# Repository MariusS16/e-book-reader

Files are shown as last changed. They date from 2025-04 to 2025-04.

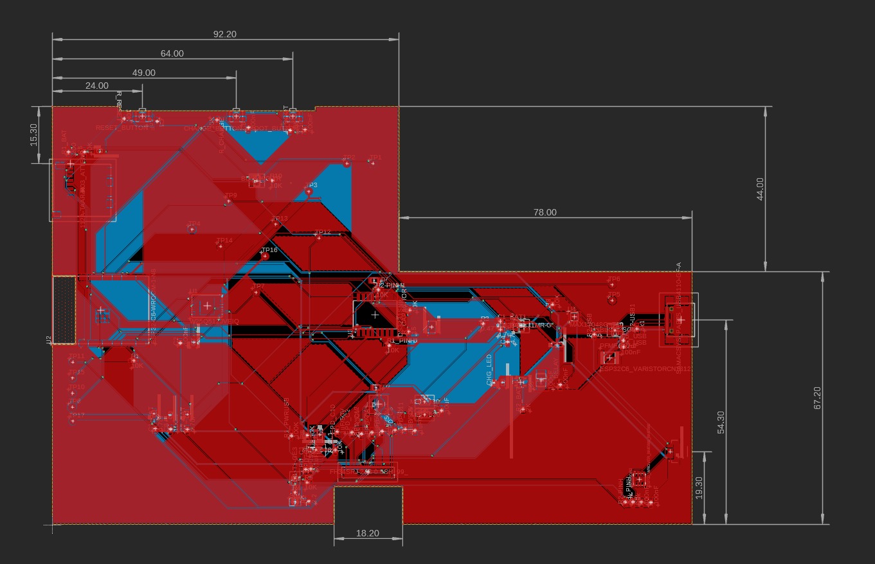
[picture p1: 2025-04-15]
Images/finalpcb.jpg

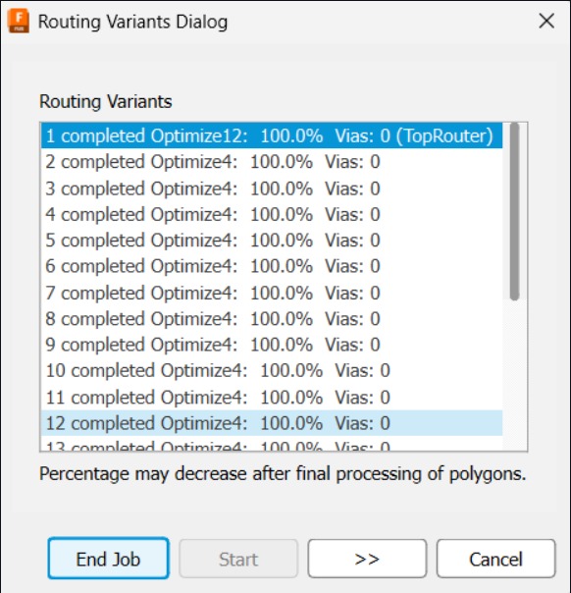
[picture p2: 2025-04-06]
Images/img4.jpg

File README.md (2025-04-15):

# README - OpenBook E-Reader

**Autor: Slincu Marius**

## Prezentare Generală

OpenBook este un e-reader open-source bazat pe microcontrollerul ESP32-C6. Dispozitivul integrează un ecran e-paper de 7.5 inch, un senzor de mediu (BME680), un sistem de monitorizare a bateriei, precum și conectivitate Wi-Fi și USB-C. Acest fisier descrie arhitectura hardware a proiectului, componentele principale și modul în care acestea sunt interconectate.

---

## Diagramă de Bloc

```

                +---------------------------+
                |     USB-C Connector       |
                | (USB Data ↔ ESP32 USB)    |
                | (ESD & Termination Prot.) |
                +-------------+-------------+
                              |
                              v
                +--------------------------+
                |       Charging IC        |<-- USB-C Power
                +-------------+------------+
                              |
                              v
                +--------------------------+
                |         Battery          |
                +-------------+------------+
                              |
                              v
                +--------------------------+
                |           LDO            |
                |       (3.3V Reg)         |
                +-------------+------------+
                              |
                              v
                      +--------------+
                      |    ESP32-C6   |
                      +------+--------+
                             |
      +----------------------+-------------------------+
      |                      |                         |
      v                      v                         v
+-----------+       +----------------+         +-----------------+
|  Display  |<----->|     BME688     |<------->| Tactile Buttons |
| (SPI 4W)  |       |   (I2C + PU)   |         |  (GPIO + RC)     |
+-----------+       +----------------+         +-----------------+
```

---
## Detalii Hardware

### ESP32-C6-WROOM-1-N8

- **Rol**: Componenta centrală de control, responsabilă pentru conectivitatea wireless și interacțiunea cu perifericele.
- **Interfețe disponibile**:
  - SPI: Utilizată pentru comunicarea cu ecranul e-paper, memoria Flash și cardul Micro SD.
  - I2C: Pentru conectarea senzorului BME680, monitorului de baterie (MAX17048) și ceasului RTC (DS3231).
  - GPIO: Utilizați pentru butoane de control și semnalizare prin LED-uri.
  - UART: Dedicat depanării și comunicației seriale.
- **Specificații tehnice**: Tactat la 160MHz, 512KB SRAM, 8MB memorie Flash integrată.

### Senzor BME680

- **Rol**: Oferă măsurători precise pentru temperatură, umiditate, presiune atmosferică și calitatea aerului.
- **Interfață**: Comunicare prin magistrala I2C cu viteză de 400kHz.
- **Eficiență energetică**: Consumă sub 1mA în funcționare și sub 1µA în repaus.

### Sistem de Alimentare

- **Baterie**: Acumulator Li-Po de 2500mAh, 3.7V.
- **Încărcare**: Controlată de MCP73831 prin portul USB-C, cu un curent maxim de 1A.
- **Monitorizare**: Realizată cu ajutorul cipului MAX17048, prin I2C.
- **Profil de consum**:
  - În activitate (Wi-Fi activ și ecran actualizat): ~150mA.
  - În standby (ecran static, fără activitate radio): ~10mA.
  - În modul deep sleep: >50µA.
  - **Autonomie estimată**: ~250 de ore la un consum mediu de 10mA.

### Butoane de Navigare

- Folosește butoane tactile Panasonic EVQPUJ02K, fiecare cu rezistență pull-up de 10KΩ.

### USB-C

- **Funcții**: Utilizat pentru încărcare (5V/1A) și transfer de date (USB 2.0).
- **Protecție**: Diode ESD (USBLC6-2SC6Y) pentru protejarea la supratensiuni.

---
# Lista de Componente (BOM)

Tabelul de mai jos prezintă componentele folosite în proiect:
| Component | Buy | Datasheet |
| --- | --- | --- |
| PFMF.050.1 | [Retailer](https://ro.mouser.com/ProductDetail/Schurter/PFMF.050.2?qs=1auRipcfynCums5v1iucSA%3D%3D) |  [Datasheet](https://ro.mouser.com/datasheet/2/358/typ_PFMF-1275918.pdf) |
| USB4110-GF-A | [Retailer](https://ro.mouser.com/ProductDetail/GCT/USB4110-GF-A?qs=KUoIvG%2F9IlYiZvIXQjyJeA%3D%3D) | [Datasheet](https://ro.mouser.com/datasheet/2/837/GCT_USB4110_Product_Drawing___20k_cycles-3455479.pdf) |
| USBLC6-2SC6Y | [Retailer](https://ro.mouser.com/ProductDetail/STMicroelectronics/USBLC6-2SC6Y?qs=gNDSiZmRJS%2FOgDexvXkdow%3D%3D) | [Datasheet](https://ro.mouser.com/datasheet/2/389/usblc6_2sc6y-1852505.pdf) |
| SD0805S020S1R0 | [Retailer](https://ro.mouser.com/ProductDetail/KYOCERA-AVX/SD0805S020S1R0?qs=jCA%252BPfw4LHbpkAoSnwrdjw%3D%3D) | [Datasheet](https://ro.mouser.com/datasheet/2/40/schottky-3165252.pdf) |
| DMG2305UX-7 | [Retailer](https://ro.mouser.com/ProductDetail/Diodes-Incorporated/DMG2305UX-7?qs=L1DZKBg7t5F%2FNBHrjfxC%252Bg%3D%3D) | [Datasheet](https://www.diodes.com/assets/Datasheets/DMG2305UX.pdf) |
| XC6220A331MR-G | [Retailer](https://ro.mouser.com/ProductDetail/Torex-Semiconductor/XC6220A331MR-G?qs=AsjdqWjXhJ8ZSWznL1J0gg%3D%3D) | [Datasheet](https://ro.mouser.com/datasheet/2/760/xc6220-3371556.pdf) |
| Condensator 100 uF TANT | [Retailer](https://ro.mouser.com/ProductDetail/KYOCERA-AVX/TAJW107M010RNJ?qs=Wtp%252Bf%2FAeVqIH8v1VxV%252B1Rg%3D%3D) | [Datasheet](https://ro.mouser.com/datasheet/2/40/TAJ-3165264.pdf) |
| 112A-TAAR-R03_ATTEND | [Retailer](https://www.digikey.ro/en/products/detail/attend-technology/112A-TAAR-R03/17633923) | [Datasheet](https://www.attend.com.tw/data/download/file/112A-TAAR-R03_Spec.pdf)
| ESP32-C6-WROOM-1-N8 | [Retailer](https://ro.mouser.com/ProductDetail/Espressif-Systems/ESP32-C6-WROOM-1-N8?qs=8Wlm6%252BaMh8ST02Gmwp74cw%3D%3D) | [Datasheet](https://ro.mouser.com/datasheet/2/891/Espressif_ESP32_C6_WROOM_1__Datasheet_V0_1_PRELIMI-3239987.pdf) |
| MCP73831 | [Retailer](https://ro.mouser.com/ProductDetail/Microchip-Technology/MCP73831T-2ACI-OT?qs=yUQqVecv4qvbBQBGbHx0Mw%3D%3D) | [Datasheet](https://ro.mouser.com/datasheet/2/268/MCP73831_Family_Data_Sheet_DS20001984H-3441711.pdf) |
| CHG_LED | [Retailer](https://store.comet.srl.ro/Catalogue/Product/40478/) | [Datasheet](https://www.snapeda.com/parts/KP-1608SURCK/Kingbright/datasheet/) |
| SI1308EDL-T1-GE3 | [Retailer](https://ro.mouser.com/ProductDetail/Vishay-Semiconductors/SI1308EDL-T1-GE3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) | [Datasheet](https://www.vishay.com/doc?63399) |
| MBR0530 | [Retailer](https://ro.mouser.com/ProductDetail/Micro-Commercial-Components-MCC/MBR0530-T?qs=9VyI4qLX4NTSXkb9ynzJnA%3D%3D) | [Datasheet](https://ro.mouser.com/datasheet/2/258/mcc_mbr0520~mbr0560sod123-1179695.pdf) |
| L1 | [Retailer](https://ro.mouser.com/ProductDetail/Wurth-Elektronik/744043680?qs=PGXP4M47uW6VkZq%252BkzjrHA%3D%3D) | [Datasheet](https://www.we-online.com/components/products/datasheet/744043680.pdf) |
| FH34SRJ-24S-0.5SH_99_ | [Retailer](https://ro.mouser.com/ProductDetail/Hirose-Connector/FH34SRJ-24S-0.5SH99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) | [Datasheet](https://ro.mouser.com/datasheet/2/185/FH34SRJ_24S_0_5SH_99__CL0580_1255_6_99_2DDrawing_0-1615044.pdf) |
| BME688 | [Retailer](https://ro.mouser.com/ProductDetail/Bosch-Sensortec/BME688?qs=IS%252B4QmGtzzqQoVDscqwx3A%3D%3D) | [Datasheet](https://ro.mouser.com/datasheet/2/783/bst_bme688_fl000-2307034.pdf) |
| BD5229G-TR | [Retailer](https://ro.mouser.com/ProductDetail/ROHM-Semiconductor/BD5229G-TR?qs=4kLU8WoGk0vvnhrrYwdszw%3D%3D) | [Datasheet](https://fscdn.rohm.com/en/products/databook/datasheet/ic/power/voltage_detector/bd52xxg-e.pdf) |
| Button | [Retailer](https://ro.mouser.com/ProductDetail/CK/KMR221GULCLFS?qs=u2NJ%252B70r0goBXaNk7IrU0Q%3D%3D) | [Datasheet](https://www.ckswitches.com/media/1479/kmr2.pdf) |
| MAX17048G+T10 | [Retailer](https://ro.mouser.com/ProductDetail/Analog-Devices-Maxim-Integrated/MAX17048G%2bT10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) | [Datasheet](https://ro.mouser.com/datasheet/2/609/MAX17048_MAX17049-3469099.pdf) |
| W25Q512JVEIQ | [Retailer](https://ro.mouser.com/ProductDetail/Winbond/W25Q512JVEIQ?qs=l7cgNqFNU1jw6svr3at6tA%3D%3D) | [Datasheet](https://ro.mouser.com/datasheet/2/949/Winbond_W25Q512JV_Datasheet-3240039.pdf) |
| PGB1010603MR | [Retailer](https://ro.mouser.com/ProductDetail/Littelfuse/PGB1010603MRHF?qs=KvZd0dN2Zg%2FuIq6icj%252BGKA%3D%3D) | [Datasheet](https://www.littelfuse.com/media?itemid=8a337998-d54d-466b-be4e-dc5bcd1f9321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) |
| QWIIC_RIGHT_ANGLE | [Retailer](https://ro.mouser.com/ProductDetail/GCT/USB4110-GF-A?qs=KUoIvG%2F9IlYiZvIXQjyJeA%3D%3D) | [Datasheet](https://ro.mouser.com/datasheet/2/837/GCT_USB4110_Product_Drawing___20k_cycles-3455479.pdf) |
| DS3231SN# | [Retailer](https://ro.mouser.com/ProductDetail/Analog-Devices-Maxim-Integrated/DS3231SN?qs=ffX8NcjNb2RmKAb9wAk9Ug%3D%3D) | [Datasheet](https://ro.mouser.com/datasheet/2/609/DS3231-3421123.pdf) |
| CPH3225A C10_SUPERCAP | [Retailer](https://ro.mouser.com/ProductDetail/Seiko-Semiconductors/CPH3225A?qs=3etwrb1wR%252BhUOph6lAO7eg%3D%3D) | [Datasheet](https://ro.mouser.com/datasheet/2/360/Seiko_Instruments_MicroBattery_E_20230330_2024Jan_-3561061.pdf) |
| Condensator 100nF | [Retailer](https://ro.mouser.com/ProductDetail/KYOCERA-AVX/06033G104ZAT2A?qs=NXubJDmysXJMPmHfVo6Z%252BA%3D%3D) | [Datasheet](https://ro.mouser.com/datasheet/2/40/KGM_Y5V-3223189.pdf) |
| Condensator 4.7uF | [Retailer](https://ro.mouser.com/ProductDetail/KYOCERA-AVX/0402ZD475MAT2A?qs=NBFAU1oqP4W4U2PCPHI0sg%3D%3D) | [Datasheet](https://ro.mouser.com/datasheet/2/40/cx5r_KGM-3223198.pdf) |
| Condensator 10uF | [Retailer](https://ro.mouser.com/ProductDetail/Samsung-Electro-Mechanics/CL10A106KQ8NNNL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) | [Datasheet](https://ro.mouser.com/datasheet/2/585/MLCC-1837944.pdf) |

## Configurare Pini ESP32-C6

| **Pin ESP32-C6** | **Funcție** | **Componentă** | **Rol** |
|---|---|---|---|
| GPIO0 | BOOT_BUTTON | Buton | Activează modul de boot la inițializare |
| GPIO1 | RESET_BUTTON | Buton | Resetare manuală |
| GPIO2 | CHANGE_BUTTON | Buton | Comutare între meniuri |
| GPIO3 | EPD_CS | Display E-Paper | Chip Select pentru SPI |
| GPIO4 | EPD_DC | Display E-Paper | Linie de control Date/Comenzi |
| GPIO5 | EPD_RST | Display E-Paper | Reset hardware pentru ecran |
| GPIO6 | EPD_BUSY | Display E-Paper | Semnal de stare pentru actualizare ecran |
| GPIO7 | SPI_MOSI | Display, Flash, SD | Linie de date pentru SPI |
| GPIO8 | SPI_MISO | Display, Flash, SD | Linie de date SPI (citire) |
| GPIO9 | SPI_SCK | Display, Flash, SD | Semnal de ceas SPI |
| GPIO10 | FLASH_CS | Memorie Flash | Chip Select pentru memorie |
| GPIO11 | SD_CS | Card Micro SD | Chip Select pentru card SD |
| GPIO12 | I2C_SDA | BME680, MAX17048, DS3231 | Linie de date I2C |
| GPIO13 | I2C_SCL | BME680, MAX17048, DS3231 | Linie de ceas I2C |
| GPIO14 | CHG_LED | LED | Indicator al procesului de încărcare |
| GPIO15 | UART_TX | Debugging | Transmitere date prin UART |
| GPIO16 | UART_RX | Debugging | Recepție date prin UART |
| GPIO17 | USB_D+ | USB-C | Linie de date USB pozitivă |
| GPIO18 | USB_D- | USB-C | Linie de date USB negativă |

**Notă**: Pinii sunt alocați conform specificațiilor ESP32-C6 și necesităților proiectului OpenBook. Mulți dintre ei pot îndeplini funcții multiple și pot fi configurați flexibil în funcție de aplicație.

**Notă**: Am avut o problema cu Fusion si mi-a dat crash aplicatia si am capatat o eroare de care nu am stiut sa scap si nu am mai putu contiuna modelul 3D, insa am facut partial din ea.







---

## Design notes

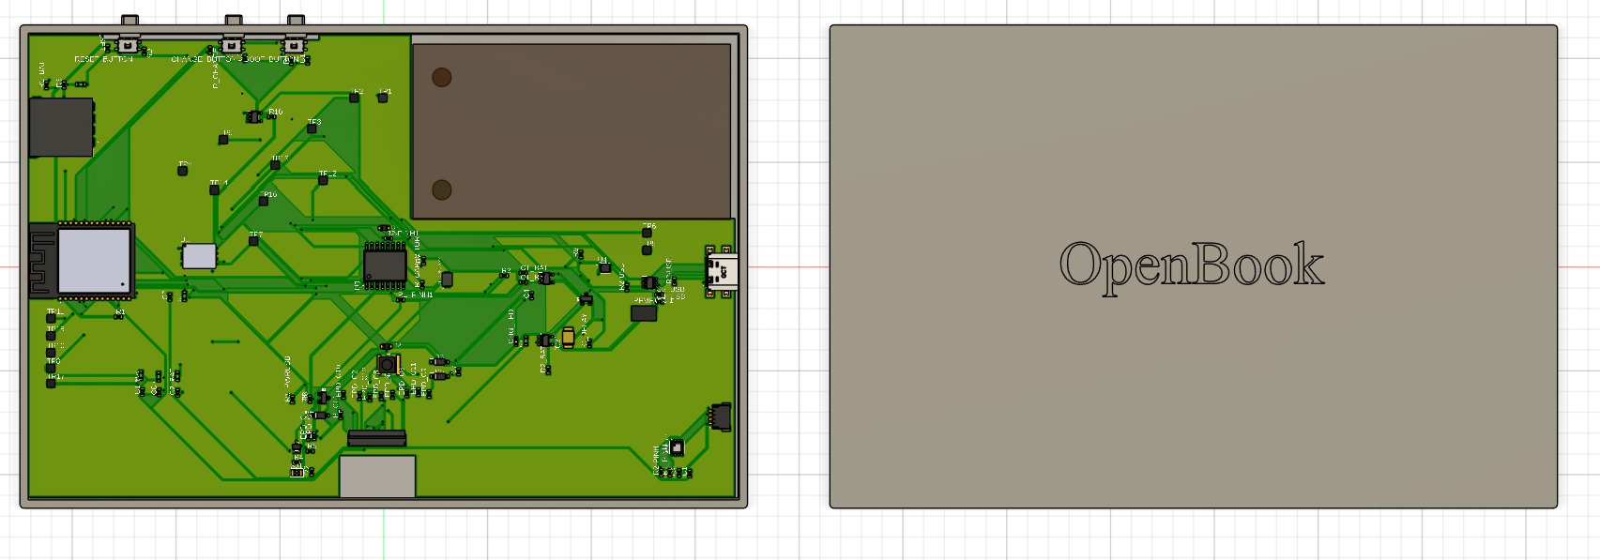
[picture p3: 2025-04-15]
Images/CarcasaFinal2.png

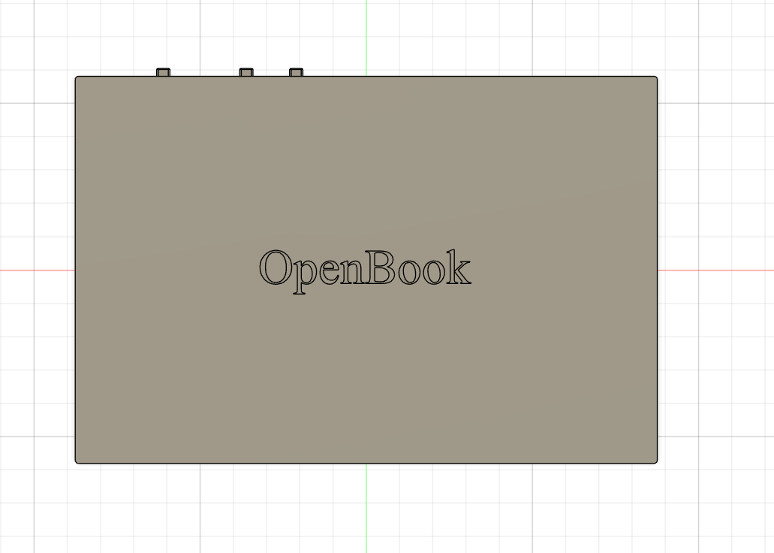
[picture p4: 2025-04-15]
Images/CarcasaFinal.png

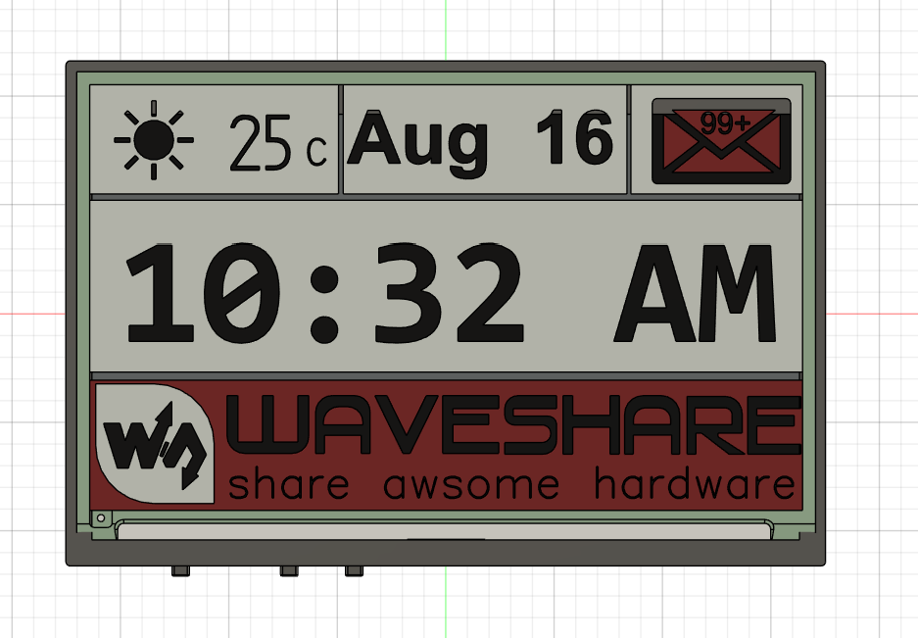
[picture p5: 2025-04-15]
Images/CarcasaFinal3.png

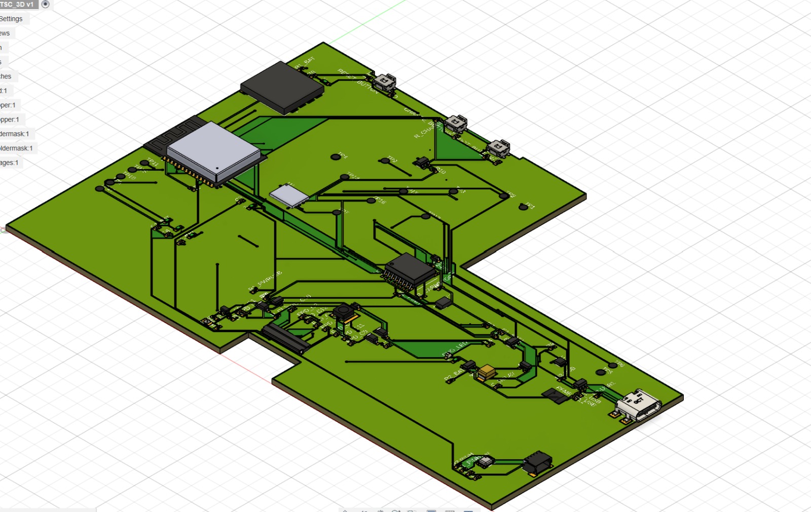
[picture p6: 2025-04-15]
Images/final3d.jpg

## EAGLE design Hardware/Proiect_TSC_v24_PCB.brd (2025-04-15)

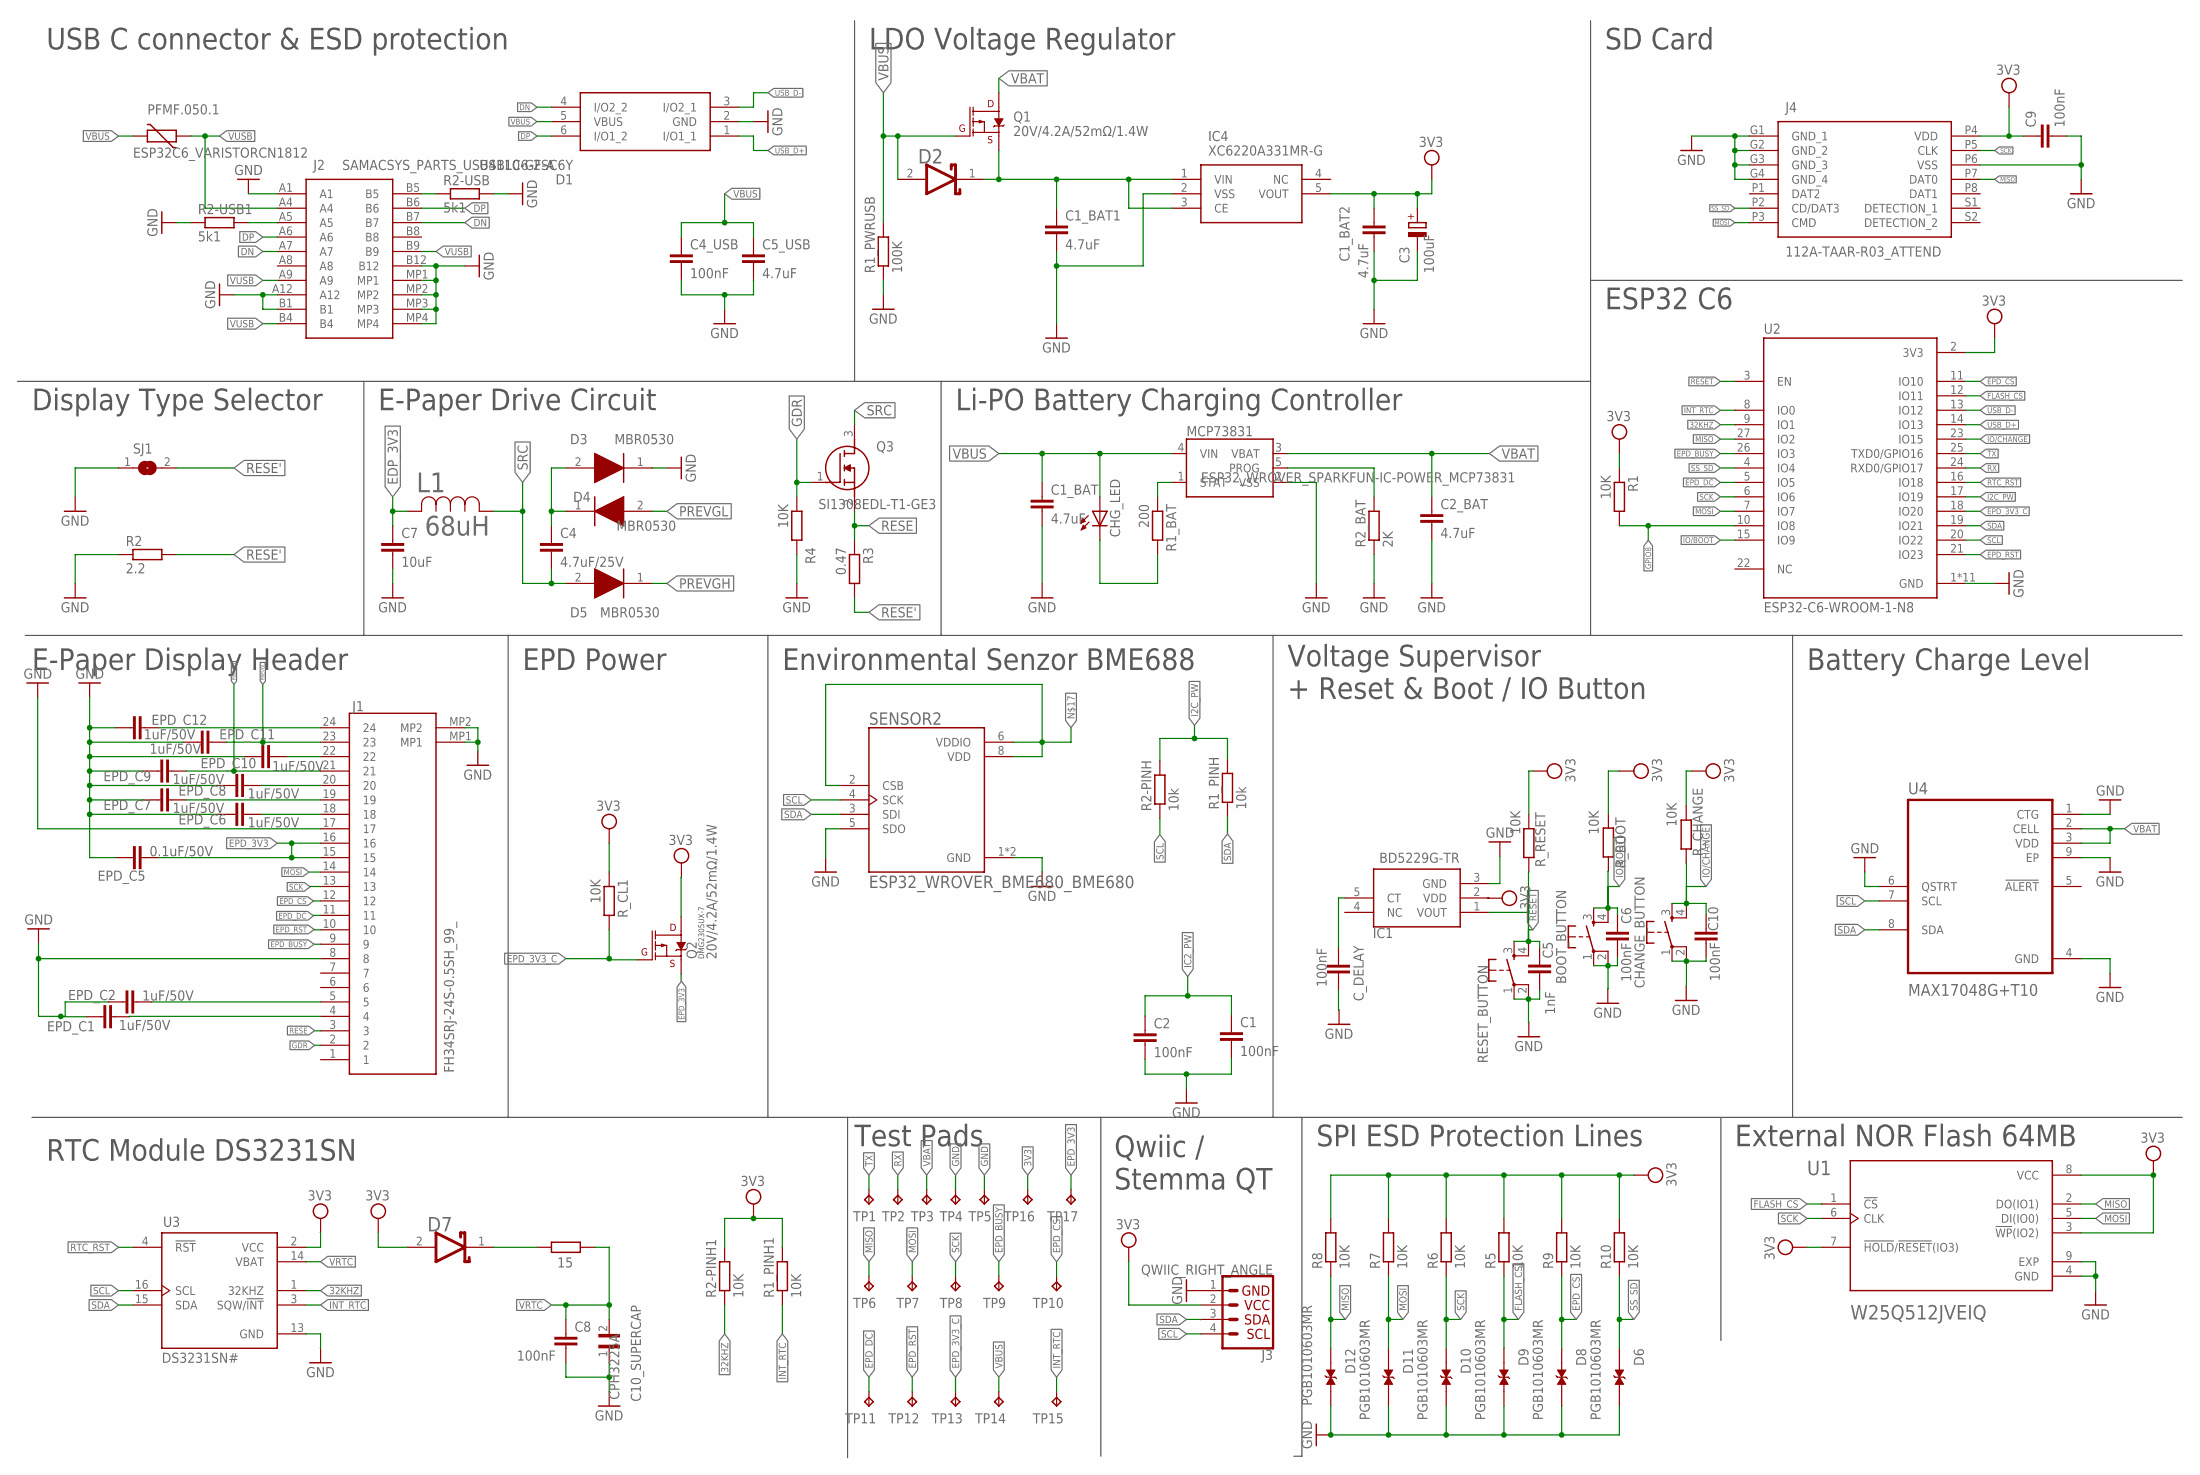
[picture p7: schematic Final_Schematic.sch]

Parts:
BOOT_BUTTON: BUTTON_CUSYOMV1; MYBUTTON
C1, C2, C4_USB, C8, C9: 100nF; ESP32_WROVER_EAGLE-LTSPICE_C0402
C1_BAT, C1_BAT1, C1_BAT2, C2_BAT, C5_USB: 4.7uF; ESP32_WROVER_EAGLE-LTSPICE_C0402
C3: 100uF; RCL_CT3528
C4: 4.7uF/25V; ESP32_WROVER_EAGLE-LTSPICE_C0402
C5: 1nF; EAGLE-LTSPICE_C0402
C6, C10: 100nF; EAGLE-LTSPICE_C0402
C7: 10uF; ESP32_WROVER_EAGLE-LTSPICE_C0402
C10_SUPERCAP: CPH3225A; CAPCP3225X100N
CHANGE_BUTTON: BUTTON_CUSYOMV1; MYBUTTON
CHG_LED: ADAFRUIT_LEDCHIP-LED0603; ADAFRUIT_CHIP-LED0603
C_DELAY: 100nF; ESP32_WROVER_EAGLE-LTSPICE_C0402
D1: USBLC6-2SC6Y; SOT95P280X145-6N
D2, D7: ESP32_WROVER_AVX---SD0805S020S1R0_AVX_SD0805S020S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; ESP32_WROVER_AVX---SD0805S020S1R0_AVX_SD0805S020S1R0_0
D3, D4, D5: MBR0530; SOD3716X135N
D6, D8, D9, D10, D11, D12: PGB1010603MR; DIOC1608X36N
EPD_C1, EPD_C2, EPD_C6, EPD_C7, EPD_C8, EPD_C9, EPD_C10, EPD_C11, EPD_C12: 1uF/50V; EAGLE-LTSPICE_C0402
EPD_C5: 0.1uF/50V; EAGLE-LTSPICE_C0402
IC1: BD5229G-TR; SOT95P280X125-5N
IC4: XC6220A331MR-G; SOT95P280X120-5N
J1: FH34SRJ-24S-0.5SH_99_; FH34SRJ24S05SH99
J2: SAMACSYS_PARTS_USB4110-GF-A; SAMACSYS_PARTS_USB4110GFA
J3: QWIIC_RIGHT_ANGLE; JST04_1MM_RA
J4: 112A-TAAR-R03_ATTEND; 112ATAARR03ATTEND
L1: 68uH; IND_4828-WE-TPC_WRE
MCP73831: ESP32_WROVER_SPARKFUN-IC-POWER_MCP73831; ESP32_WROVER_SPARKFUN-IC-POWER_SOT23-5
PFMF.050.1: ESP32C6_VARISTORCN1812; ESP32C6_VARISTOR_CT/CN1812
Q1, Q2: 20V/4.2A/52mΩ/1.4W; ESP32_WROVER_SPARKFUN-DISCRETESEMI_SOT23-3
Q3: SI1308EDL-T1-GE3; SOT65P210X110-3N
R1, R1_PINH1, R2-PINH1, R4, R5, R6, R7, R8, R9, R10: 10K; ESP32_WROVER_EAGLE-LTSPICE_R0402
R1_BAT: 200; ESP32_WROVER_EAGLE-LTSPICE_R0402
R1_PINH, R2-PINH: 10k; ESP32_WROVER_EAGLE-LTSPICE_R0402
R1_PWRUSB: 100K; ESP32_WROVER_EAGLE-LTSPICE_R0402
R2: 2.2; ESP32_WROVER_EAGLE-LTSPICE_R0402
R2-USB, R2-USB1: 5k1; ESP32_WROVER_EAGLE-LTSPICE_R0402
R2_BAT: 2K; ESP32_WROVER_EAGLE-LTSPICE_R0402
R3: 0.47; ESP32_WROVER_EAGLE-LTSPICE_R0402
RESET_BUTTON: BUTTON_CUSYOMV1; MYBUTTON
R_BOOT: 10K; ESP32_WROVER_EAGLE-LTSPICE_R0402
R_CAPACITOR: 15; ESP32_WROVER_EAGLE-LTSPICE_R0402
R_CHANGE: 10K; ESP32_WROVER_EAGLE-LTSPICE_R0402
R_CL1: 10K; ESP32_WROVER_EAGLE-LTSPICE_R0402
R_RESET: 10K; ESP32_WROVER_EAGLE-LTSPICE_R0402
SENSOR2: ESP32_WROVER_BME680_BME680; ESP32_WROVER_BME680_PSON80P300X300X100-8N
SJ1: SJ
TP1, TP2, TP3, TP4, TP5, TP6, TP7, TP8, TP9, TP10, TP11, TP12, TP13, TP14, TP15, TP16, TP17: TPTP20R; TP20R
U1: W25Q512JVEIQ; SON127P600X800X80-9N
U2: ESP32-C6-WROOM-1-N8; XCVR_ESP32-C6-WROOM-1-N8
U3: DS3231SN#; SOIC127P1032X265-16N
U4: MAX17048G+T10; SON50P200X200X80-9N

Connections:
3V3: C1_BAT2.1, C3.+, C9.1, D7.2 (ANODE), IC4.5 (VOUT), J3.2, J4.P4 (VDD), Q2.3 (D), R1.1, R1_PINH1.2, R2-PINH1.2, R5.2, R6.2, R7.2, R8.2, R9.2, R10.2, R_BOOT.2, R_CHANGE.2, R_CL1.1, R_RESET.2, TP16.TP, U1.3 (!WP!(IO2)), U1.7 (!HOLD!/!RESET!(IO3)), U1.8 (VCC), U2.2 (3V3), U3.2 (VCC)
32KHZ: R2-PINH1.1, U2.9 (IO1), U3.1 (32KHZ)
DN: D1.4 (I/O2_2), J2.A7, J2.B7
DP: D1.6 (I/O1_2), J2.A6, J2.B6
EDP_3V3: C7.1, L1.2
EPD_3V3: EPD_C5.2, J1.15, J1.16, Q2.2 (S), TP17.TP
EPD_3V3_C: Q2.1 (G), R_CL1.2, TP13.TP, U2.18 (IO20)
EPD_BUSY: J1.9, TP9.TP, U2.26 (IO3)
EPD_CS: D8.1, J1.12, R9.1, TP10.TP, U2.11 (IO10)
EPD_DC: J1.11, TP11.TP, U2.5 (IO5)
EPD_RST: J1.10, TP12.TP, U2.21 (IO23)
FLASH_CS: D9.1, R5.1, U1.1 (!CS), U2.12 (IO11)
GDR: J1.2, Q3.1 (G), R4.1
GND: BOOT_BUTTON.1, BOOT_BUTTON.2, C1.2, C1_BAT.2, C1_BAT1.2, C1_BAT2.2, C2.2, C2_BAT.2, C3.-, C4_USB.2, C5.2, C5_USB.2, C6.2, C7.2, C8.2, C9.2, C10.2, C10_SUPERCAP.1, CHANGE_BUTTON.1, CHANGE_BUTTON.2, C_DELAY.2, D1.2 (GND), D3.1 (K), D6.2, D8.2, D9.2, D10.2, D11.2, D12.2, EPD_C1.1, EPD_C2.1, EPD_C5.1, EPD_C6.1, EPD_C7.1, EPD_C8.1, EPD_C9.1, EPD_C10.1, EPD_C11.1, EPD_C12.1, IC1.3 (GND), IC4.2 (VSS), J1.8, J1.17, J1.MP1, J1.MP2, J2.A1, J2.A12, J2.B1, J2.B12, J2.MP1, J2.MP2, J2.MP3, J2.MP4, J3.1, J4.G1 (GND_1), J4.G2 (GND_2), J4.G3 (GND_3), J4.G4 (GND_4), J4.P6 (VSS), MCP73831.2 (VSS), R1_PWRUSB.1, R2.1, R2-USB.2, R2-USB1.1, R2_BAT.1, R4.2, RESET_BUTTON.1, RESET_BUTTON.2, SENSOR2.1 (GND), SENSOR2.5 (SDO), SENSOR2.7 (GND), SJ1.1, TP4.TP, TP5.TP, U1.4 (GND), U1.9 (EXP), U2.1 (GND), U2.28 (GND), U2.29_1 (GND), U2.29_2 (GND), U2.29_3 (GND), U2.29_4 (GND), U2.29_5 (GND), U2.29_6 (GND), U2.29_7 (GND), U2.29_8 (GND), U2.29_9 (GND), U3.13 (GND), U4.1 (CTG), U4.4 (GND), U4.6 (QSTRT), U4.9 (EP)
GPIO8: R1.2, U2.10 (IO8)
I2C_PW: R1_PINH.2, R2-PINH.2, U2.17 (IO19)
IC2_PW: C1.1, C2.1
INT_RTC: R1_PINH1.1, TP15.TP, U2.8 (IO0), U3.3 (SQW/!INT)
IO/BOOT: BOOT_BUTTON.3, BOOT_BUTTON.4, C6.1, R_BOOT.1, U2.15 (IO9)
IO/CHANGE: C10.1, CHANGE_BUTTON.3, CHANGE_BUTTON.4, R_CHANGE.1, U2.23 (IO15)
MISO: D12.1, J4.P7 (DAT0), R8.1, TP6.TP, U1.2 (DO(IO1)), U2.27 (IO2)
MOSI: D11.1, J1.14, J4.P3 (CMD), R7.1, TP7.TP, U1.5 (DI(IO0)), U2.7 (IO7)
unnamed: EPD_C10.2, J1.22
unnamed: C1_BAT1.1, D2.1 (CATHODE), IC4.1 (VIN), IC4.3 (CE), Q1.2 (S)
unnamed: MCP73831.5 (PROG), R2_BAT.2
unnamed: EPD_C8.2, J1.20
unnamed: J2.B5, R2-USB.1
unnamed: C4.1, D3.2 (A), D4.1 (K)
unnamed: MCP73831.1 (STAT), R1_BAT.1
unnamed: CHG_LED.C, R1_BAT.2
unnamed: EPD_C7.2, J1.19
unnamed: J2.A5, R2-USB1.2
unnamed: EPD_C6.2, J1.18
unnamed: EPD_C12.2, J1.24
unnamed: D7.1 (CATHODE), R_CAPACITOR.2
unnamed: EPD_C2.2, J1.5
unnamed: EPD_C1.2, J1.4
unnamed: SENSOR2.2 (CSB), SENSOR2.6 (VDDIO), SENSOR2.8 (VDD)
unnamed: C_DELAY.1, IC1.5 (CT)
PREVGH: D5.1 (K), EPD_C9.2, J1.21
PREVGL: D4.2 (A), EPD_C11.2, J1.23
RESE: J1.3, Q3.2 (S), R3.1
RESE': R2.2, R3.2, SJ1.2
RESET: C5.1, IC1.1 (VOUT), RESET_BUTTON.3, RESET_BUTTON.4, R_RESET.1, U2.3 (EN)
RTC_RST: U2.16 (IO18), U3.4 (!RST)
RX: TP2.TP, U2.24 (RXD0/GPIO17)
SCK: D10.1, J1.13, J4.P5 (CLK), R6.1, TP8.TP, U1.6 (CLK), U2.6 (IO6)
SCL: J3.4, R2-PINH.1, SENSOR2.4 (SCK), U2.20 (IO22), U3.16 (SCL), U4.7 (SCL)
SDA: J3.3, R1_PINH.1, SENSOR2.3 (SDI), U2.19 (IO21), U3.15 (SDA), U4.8 (SDA)
SRC: C4.2, D5.2 (A), L1.1, Q3.3 (D)
SS_SD: D6.1, J4.P2 (CD/DAT3), R10.1, U2.4 (IO4)
TX: TP1.TP, U2.25 (TXD0/GPIO16)
USB_D+: D1.1 (I/O1_1), U2.14 (IO13)
USB_D-: D1.3 (I/O2_1), U2.13 (IO12)
VBAT: C2_BAT.1, MCP73831.3 (VBAT), Q1.3 (D), TP3.TP, U4.2 (CELL), U4.3 (VDD)
VBUS: C1_BAT.1, C4_USB.1, C5_USB.1, CHG_LED.A, D1.5 (VBUS), D2.2 (ANODE), MCP73831.4 (VIN), PFMF.050.1.2, Q1.1 (G), R1_PWRUSB.2, TP14.TP
VRTC: C8.1, C10_SUPERCAP.2, R_CAPACITOR.1, U3.14 (VBAT)
VUSB: J2.A4, J2.A9, J2.B4, J2.B9, PFMF.050.1.1

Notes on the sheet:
USB C connector & ESD protection
LDO Voltage Regulator
SD Card
ESP32 C6
Li-PO Battery Charging Controller
Display Type Selector
E-Paper Drive Circuit
Battery Charge Level
External NOR Flash 64MB
E-Paper Display Header
DMG2305UX-7
EPD Power
Environmental Senzor BME688
Voltage Supervisor + Reset & Boot / IO Button
RTC Module DS3231SN
Qwiic / Stemma QT
Test Pads
SPI ESD Protection Lines

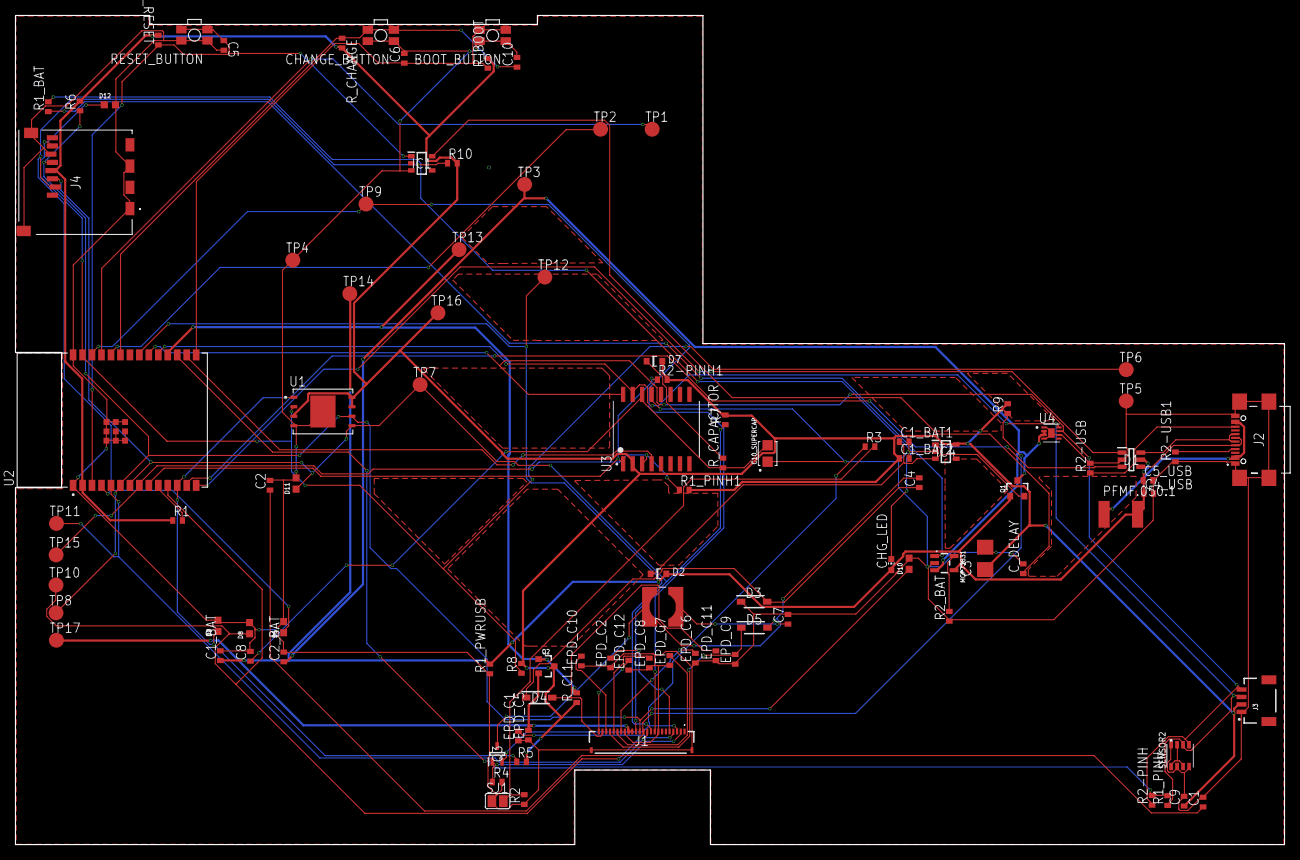
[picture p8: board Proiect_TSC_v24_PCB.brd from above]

Board: 2 copper layers, 170.2 x 111.2 mm, 103 parts (0 on the bottom side), 58 nets.

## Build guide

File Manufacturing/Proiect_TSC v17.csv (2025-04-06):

Partlist exported from Fusion Hub: MariusS16   Project: Admin Project  Board: Proiect_TSC v17 at 06-Apr-25 10:52 PM
Qty Value                                                                          Device                                                                         Package                                                Parts                                                                                       Description                                                                                                                                                                                                                                                                                                                                                                                                                                                                                          ARROW_PART_NUMBER ARROW_PRICE-STOCK AVAILABILITY CENTROID_NOT_SPECIFIED CHECK_PRICES                                                                           COPYRIGHT                                                DATASHEET                              DESCRIPTION                                                                                        DIGIKEY_DESCRIPTION                                                                                                                                                                                                      DIGIKEY_PART_NUMBER                           HEIGHT                                                                                L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
1                                                                                  ADAFRUIT_LEDCHIP-LED0603                                                       ADAFRUIT_CHIP-LED0603                                  CHG_LED                                                                                     LED
1                                                                                  SJ                                                                             SJ                                                     SJ1                                                                                         SMD solder JUMPER                                                                                                                                                                                                                                                                                                                                                                                                                                                                                                                                                                                                                                                                                                                                                                                                                                                                                                                                                                                                                                                                                                                                                                                                                    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
1   0.1uF/50V                                                                      EAGLE-LTSPICE_CC0402                                                           EAGLE-LTSPICE_C0402                                    EPD_C5                                                                                      CAPACITOR, European symbol                                                                                                                                                                                                                                                                                                                                                                                                                                                                                                                                                                                                                                                                                                                                                                                                                                                                                                                                                                                                                                                                                                                                                                                                           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
1   0.47                                                                           ESP32_WROVER_EAGLE-LTSPICE_RR0402                                              ESP32_WROVER_EAGLE-LTSPICE_R0402                       R3                                                                                          RESISTOR, European symbol                                                                                                                                                                                                                                                                                                                                                                                                                                                                                                                                                                                                                                                                                                                                                                                                                                                                                                                                                                                                                                                                                                                                                                                                            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
1   100K                                                                           ESP32_WROVER_EAGLE-LTSPICE_RR0402                                              ESP32_WROVER_EAGLE-LTSPICE_R0402                       R1_PWRUSB                                                                                   RESISTOR, European symbol                                                                                                                                                                                                                                                                                                                                                                                                                                                                                                                                                                                                                                                                                                                                                                                                                                                                                                                                                                                                                                                                                                                                                                                                            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
2   100nF                                                                          EAGLE-LTSPICE_CC0402                                                           EAGLE-LTSPICE_C0402                                    C6, C10                                                                                     CAPACITOR, European symbol                                                                                                                                                                                                                                                                                                                                                                                                                                                                                                                                                                                                                                                                                                                                                                                                                                                                                                                                                                                                                                                                                                                                                                                                           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
6   100nF                                                                          ESP32_WROVER_EAGLE-LTSPICE_CC0402                                              ESP32_WROVER_EAGLE-LTSPICE_C0402                       C1, C2, C4_USB, C8, C9, C_DELAY                                                             CAPACITOR, European symbol                                                                                                                                                                                                                                                                                                                                                                                                                                                                                                                                                                                                                                                                                                                                                                                                                                                                                                                                                                                                                                                                                                                                                                                                           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

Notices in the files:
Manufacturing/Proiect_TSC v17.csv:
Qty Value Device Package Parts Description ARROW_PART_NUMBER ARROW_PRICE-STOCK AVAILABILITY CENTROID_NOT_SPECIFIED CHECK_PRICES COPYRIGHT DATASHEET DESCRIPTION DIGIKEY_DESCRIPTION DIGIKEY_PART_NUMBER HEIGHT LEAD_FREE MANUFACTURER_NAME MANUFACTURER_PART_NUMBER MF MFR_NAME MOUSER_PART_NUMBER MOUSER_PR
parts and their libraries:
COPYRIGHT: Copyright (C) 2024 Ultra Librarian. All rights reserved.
